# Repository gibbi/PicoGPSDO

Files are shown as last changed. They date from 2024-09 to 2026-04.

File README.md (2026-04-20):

# picoExtRef — GPS-disciplined OCXO reference (Pico)

RP2040 firmware that steers an OCXO via PWM (“DAC”), reads u-blox GNSS time over UART (UBX), and closes a two-stage servo: coarse steering from NAV-CLOCK and fine steering from TIM-TP `qErr`. A small Flask dashboard on the host tails USB CDC for live plots and tuning.

**Hardware upstream:** this tree is based on [gibbi/PicoGPSDO](https://github.com/gibbi/PicoGPSDO) (schematics, KiCad, and notes under `hardware/`). Presentation context: European GNU Radio Days 2024 — [talk on YouTube](https://www.youtube.com/watch?v=h3X4QuF_BUM).

---

## Web UI screenshot

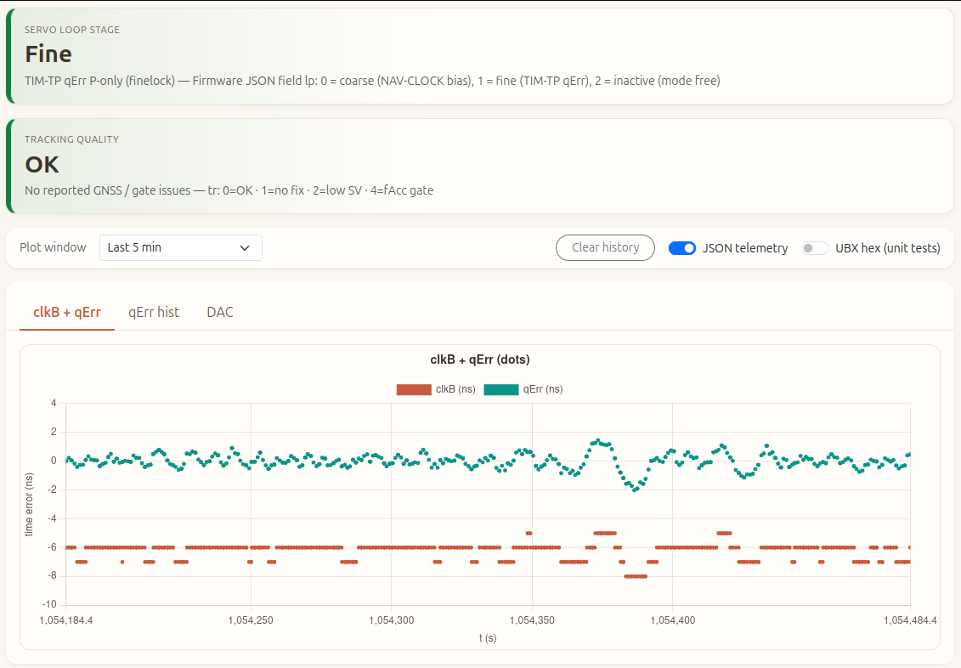
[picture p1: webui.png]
GPSDO web dashboard


## Repository layout and components

| Area | Role |
|---|---|
| **`src/main.c`** | Boot, PWM DAC / 26 MHz ref clock, main loop, JSON telemetry, USB CLI polling, fine-mode edge tracker integration, fractional DAC accumulation. |
| **`src/ubx.c`**, **`src/ubx_rx.c`** | UART RX (frame assembly + checksum), UBX decode, fills `current_gps_data` (NAV-CLOCK, TIM-TP, PVT, etc.). |
| **`include/ubx_clean.h`** | Shared GPS/UBX structs and packet layout used by the parser. |
| **`src/gpsdo_control.c`**, **`include/gpsdo_control.h`** | Finelock hysteresis, coarse/fine control outputs (`u_ns`), NAV-CLOCK bias handling, telemetry `tr` flags. |
| **`src/gpsdo_tune.c`**, **`include/gpsdo_tune.h`** | Runtime tunables and USB one-line CLI (`kp`, `fine_mode`, gates, etc.). |
| **`include/display.h`** | SSD1306 OLED over I2C (optional); live status text on the module. |
| **`pico_gpsdo_web.py`** | Flask host app: reads Pico USB serial, parses `{…}` telemetry, serves charts, tune forms, log tail, optional series clear. |
| **`pico.py`** | Developer entrypoint: `clean` / `build` / `flash` / `webserver` / `lint` (see script header for caveats on `build/` paths). |
| **`CMakeLists.txt`**, **`boards/`** | Pico SDK project, board hooks. |
| **`hardware/`** | From [PicoGPSDO](https://github.com/gibbi/PicoGPSDO): PCB and hardware documentation (see `hardware/Readme.md`). |
| **`tests/`** | Small host-side tests (e.g. UBX RX framing). |

---

## Data flow (short)

1. **u-blox** → UART0 → UBX frames → `current_gps_data` (`clkB`, `qErr`, `dac`, fix, etc.).
2. **Servo** (when `mode servo`): coarse on `clkD_bias` when bias steps; fine on `qErr` (P-only or edge mode) in finelock.
3. **USB CDC** → compact JSON lines for the host **web UI** and `printf` debugging.

---

## Quick start

```bash
# Firmware (needs Pico SDK in environment per Pico docs)
./pico.py build
./pico.py flash          # optional: ./pico.py flash --webserver

# Web dashboard only (USB serial to the Pico)
pip install -r requirements.txt
./pico.py webserver      # or: python3 pico_gpsdo_web.py … per pico.py usage
```

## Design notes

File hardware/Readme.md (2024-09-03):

# Hardware Description

This folder holds the hardware documentation for the 26MHz testbed. 

## Todo:

- [x] push kicad projects
- [ ] document antennuator values
- [ ] document ublox modification
- [ ] document oscillator swap

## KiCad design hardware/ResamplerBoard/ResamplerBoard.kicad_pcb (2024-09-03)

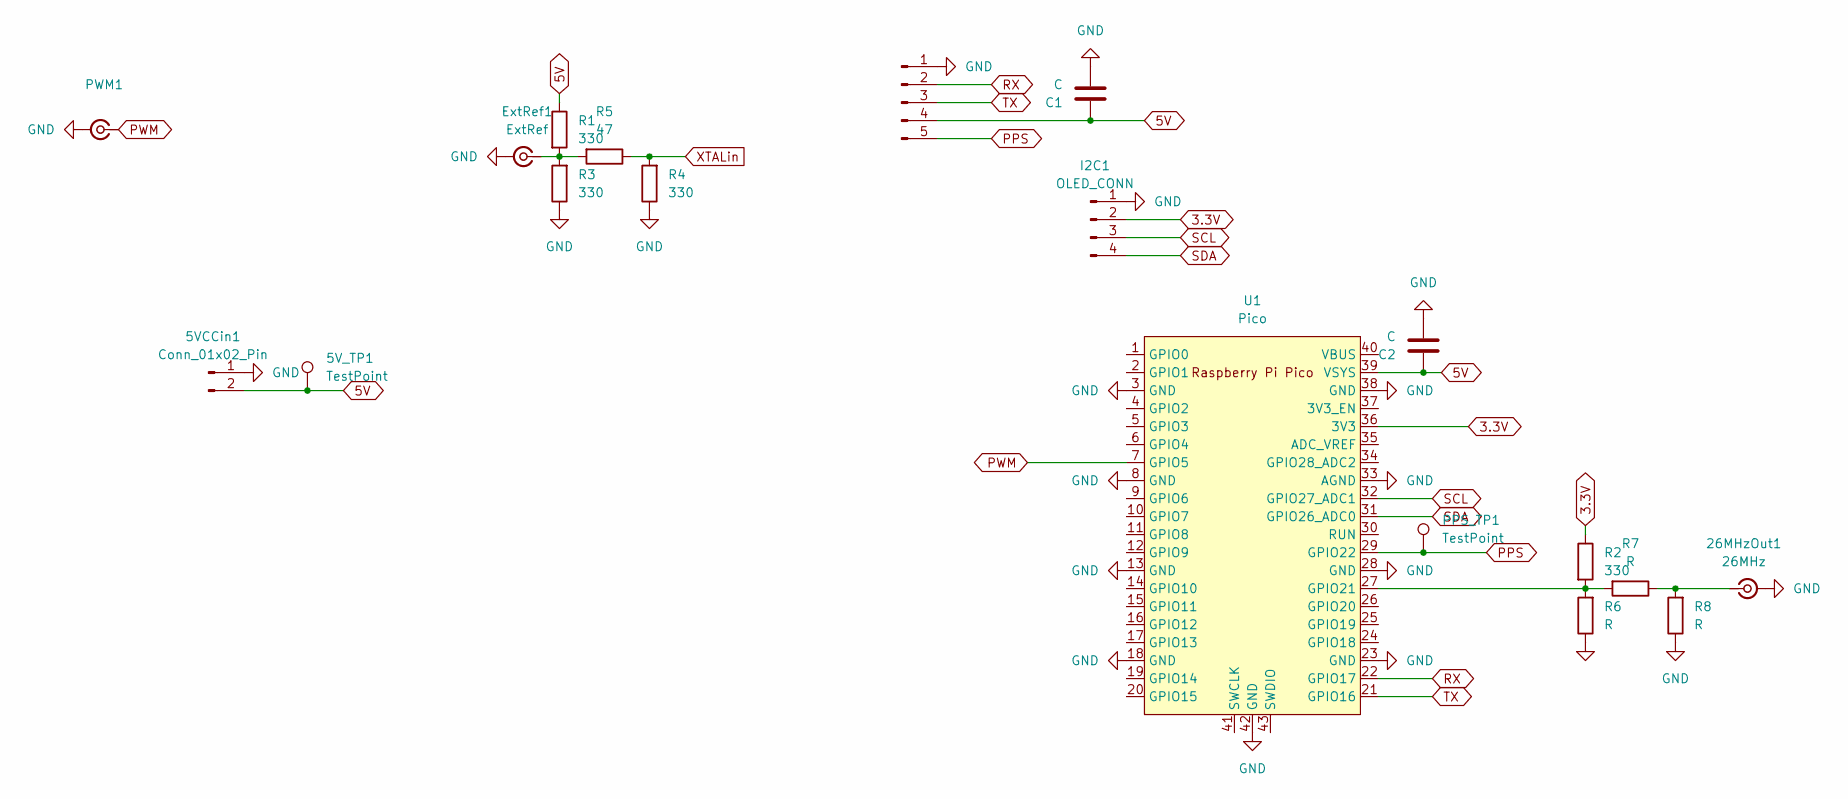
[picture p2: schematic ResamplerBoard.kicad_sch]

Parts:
5VCCin1: Conn_01x02_Pin; PinHeader_1x02_5VIN
5V_TP1: TestPoint; TestPoint_Pad_D2.0mm
26MHzOut1: 26MHz; SMA_EDGE_GIBBI
C1, C2: C; C_1210_3225Metric_Pad1.33x2.70mm_HandSolder
ExtRef1: ExtRef; SMA_EDGE_GIBBI
GPS_UART1: 9600; GPS_HEADER
I2C1: OLED_CONN; 128x64OLED
PPS_TP1: TestPoint; TestPoint_Pad_D2.0mm
PWM1: PWM; SMA_EDGE_GIBBI
R1, R2, R3, R4: 330; R_1210_3225Metric_Pad1.30x2.65mm_HandSolder
R5: 47; R_1210_3225Metric_Pad1.30x2.65mm_HandSolder
R6, R7, R8: R; R_1210_3225Metric_Pad1.30x2.65mm_HandSolder
U1: Pico; RPi_Pico_SMD_TH_NO_SILK_NO_HOLE

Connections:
3.3V: I2C1.2, R2.1, U1.36 (3V3)
5V: 5VCCin1.2, 5V_TP1.1, C1.1, C2.1, GPS_UART1.4, R1.1, U1.39 (VSYS)
GND: 5VCCin1.1, 26MHzOut1.2 (Ext), C1.2, C2.2, ExtRef1.2 (Ext), GPS_UART1.1, I2C1.1, PWM1.2 (Ext), R3.1, R4.1, R6.1, R8.1, U1.3 (GND), U1.8 (GND), U1.13 (GND), U1.18 (GND), U1.23 (GND), U1.28 (GND), U1.33 (AGND), U1.38 (GND), U1.42 (GND)
unnamed: 26MHzOut1.1 (In), R7.1, R8.2
unnamed: ExtRef1.1 (In), R1.2, R3.2, R5.2
unnamed: R2.2, R6.2, R7.2, U1.27 (GPIO21)
PPS: GPS_UART1.5, PPS_TP1.1, U1.29 (GPIO22)
PWM: PWM1.1 (In), U1.7 (GPIO5)
RX: GPS_UART1.2, U1.22 (GPIO17)
SCL: I2C1.3, U1.32 (GPIO27_ADC1)
SDA: I2C1.4, U1.31 (GPIO26_ADC0)
TX: GPS_UART1.3, U1.21 (GPIO16)
XTALin: R4.2, R5.1

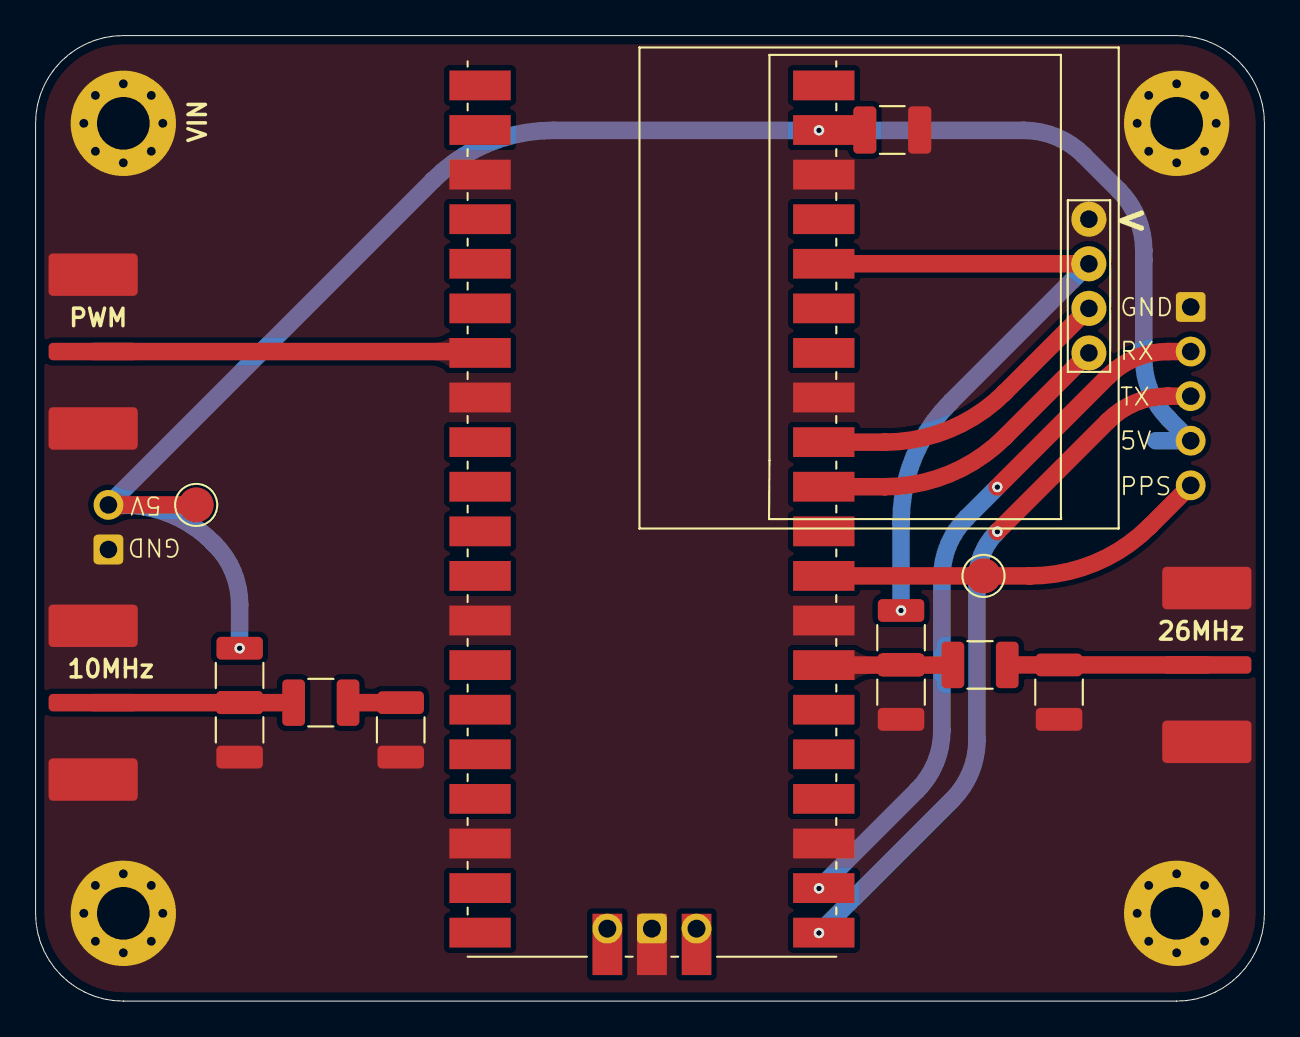
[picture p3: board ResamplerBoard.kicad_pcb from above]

Board: 2 copper layers, 70.0 x 55.0 mm, 19 parts (1 on the bottom side), 13 nets.

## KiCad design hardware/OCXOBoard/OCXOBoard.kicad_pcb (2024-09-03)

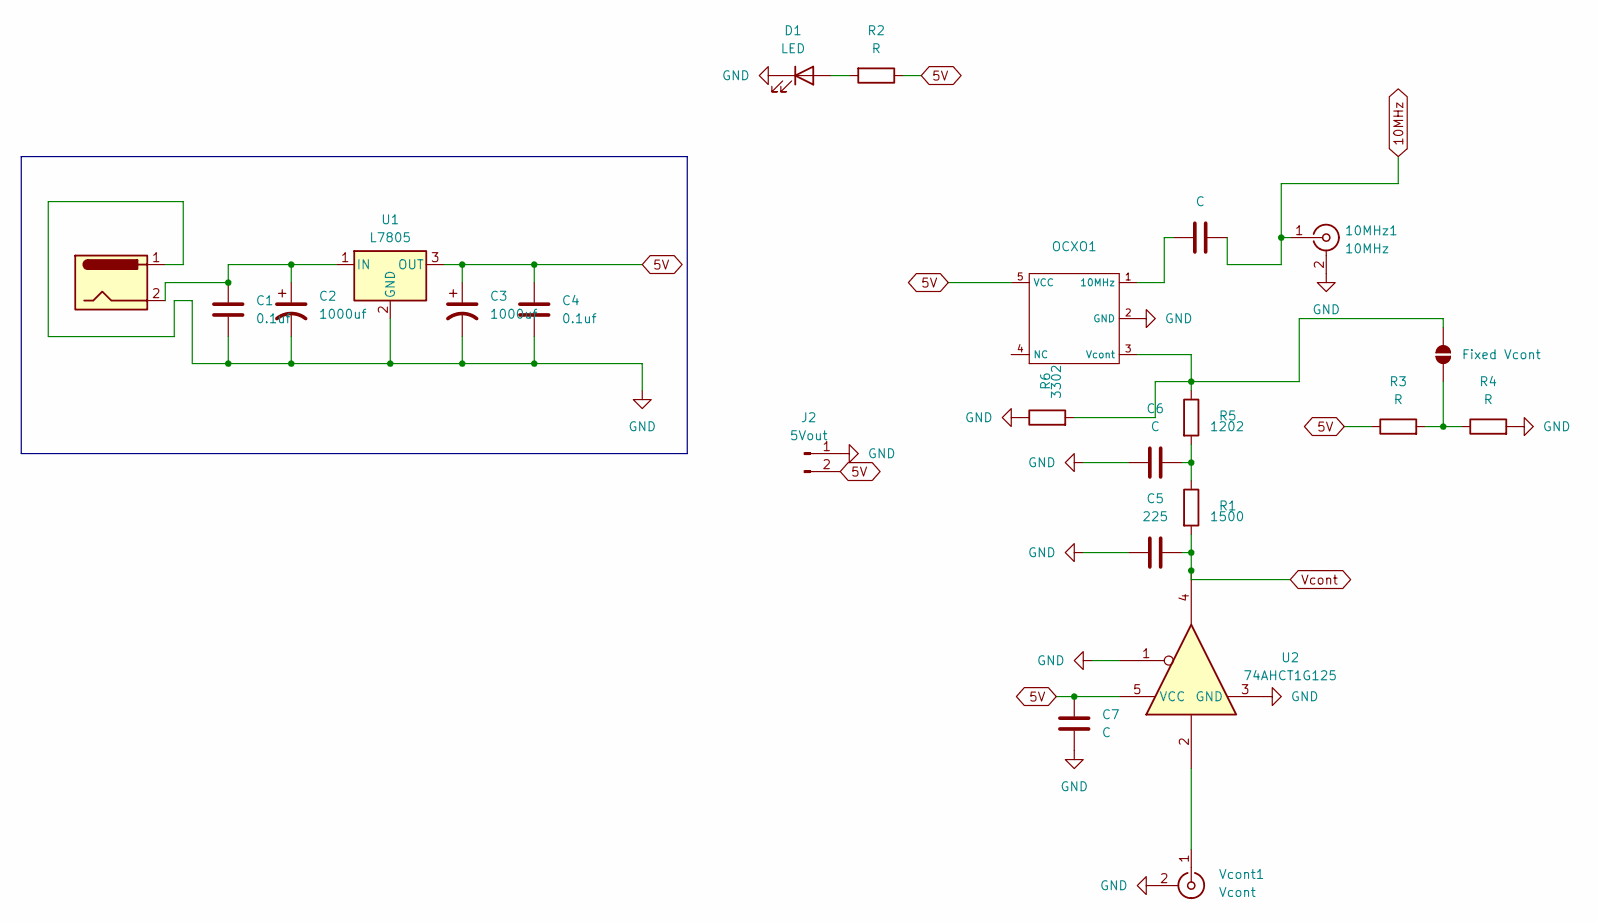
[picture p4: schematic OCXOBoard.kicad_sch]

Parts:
10MHz1: 10MHz; SMA_EDGE_GIBBI
C1, C4: 0.1uf; C_1210_3225Metric_Pad1.33x2.70mm_HandSolder
C2, C3: 1000uf; CP_EIA-7343-43_Kemet-X_Pad2.25x2.55mm_HandSolder
C5: 225; C_1210_3225Metric_Pad1.33x2.70mm_HandSolder
C6, C7: C; C_1210_3225Metric_Pad1.33x2.70mm_HandSolder
C8: C; C_0805_2012Metric_Pad1.18x1.45mm_HandSolder
D1: LED; D_1210_3225Metric_Pad1.42x2.65mm_HandSolder
FixedVcont1: Fixed Vcont; SolderJumper-2_P1.3mm_Open_RoundedPad1.0x1.5mm
J1: DC Connector; AMASS_XT30PW-M_1x02_P2.50mm_Horizontal
J2: 5Vout; Simple5V
OCXO1: MULTI_XO
R1: 1500; R_1210_3225Metric_Pad1.30x2.65mm_HandSolder
R2, R3, R4: R; R_1210_3225Metric_Pad1.30x2.65mm_HandSolder
R5: 1202; R_1210_3225Metric_Pad1.30x2.65mm_HandSolder
R6: 3302; R_1210_3225Metric_Pad1.30x2.65mm_HandSolder
U1: L7805; TO-7805
U2: 74AHCT1G125; SOT-23-5_HandSoldering
Vcont1: Vcont; SMA_EDGE_GIBBI

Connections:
5V: C3.1, C4.1, C7.2, J2.2, OCXO1.5 (VCC), R2.1, R3.1, U1.3 (OUT), U2.5 (VCC)
10MHz: 10MHz1.1 (In), C8.2
GND: 10MHz1.2 (Ext), C1.2, C2.2, C3.2, C4.2, C5.1, C6.1, C7.1, D1.1 (K), J1.1, J2.1, OCXO1.2 (GND), R4.2, R6.1, U1.2 (GND), U2.1, U2.3 (GND), Vcont1.2 (Ext)
unnamed: C6.2, R1.1, R5.2
unnamed: D1.2 (A), R2.2
unnamed 5: FixedVcont1.1 (A), R3.2, R4.1; also elsewhere on the board
unnamed 6: FixedVcont1.2 (B), OCXO1.3 (Vcont), R5.1, R6.2; also elsewhere on the board
unnamed: C8.1, OCXO1.1 (10MHz)
unnamed: C1.1, C2.1, J1.2, U1.1 (IN)
unnamed: U2.2, Vcont1.1 (In)
Vcont: C5.2, R1.2, U2.4

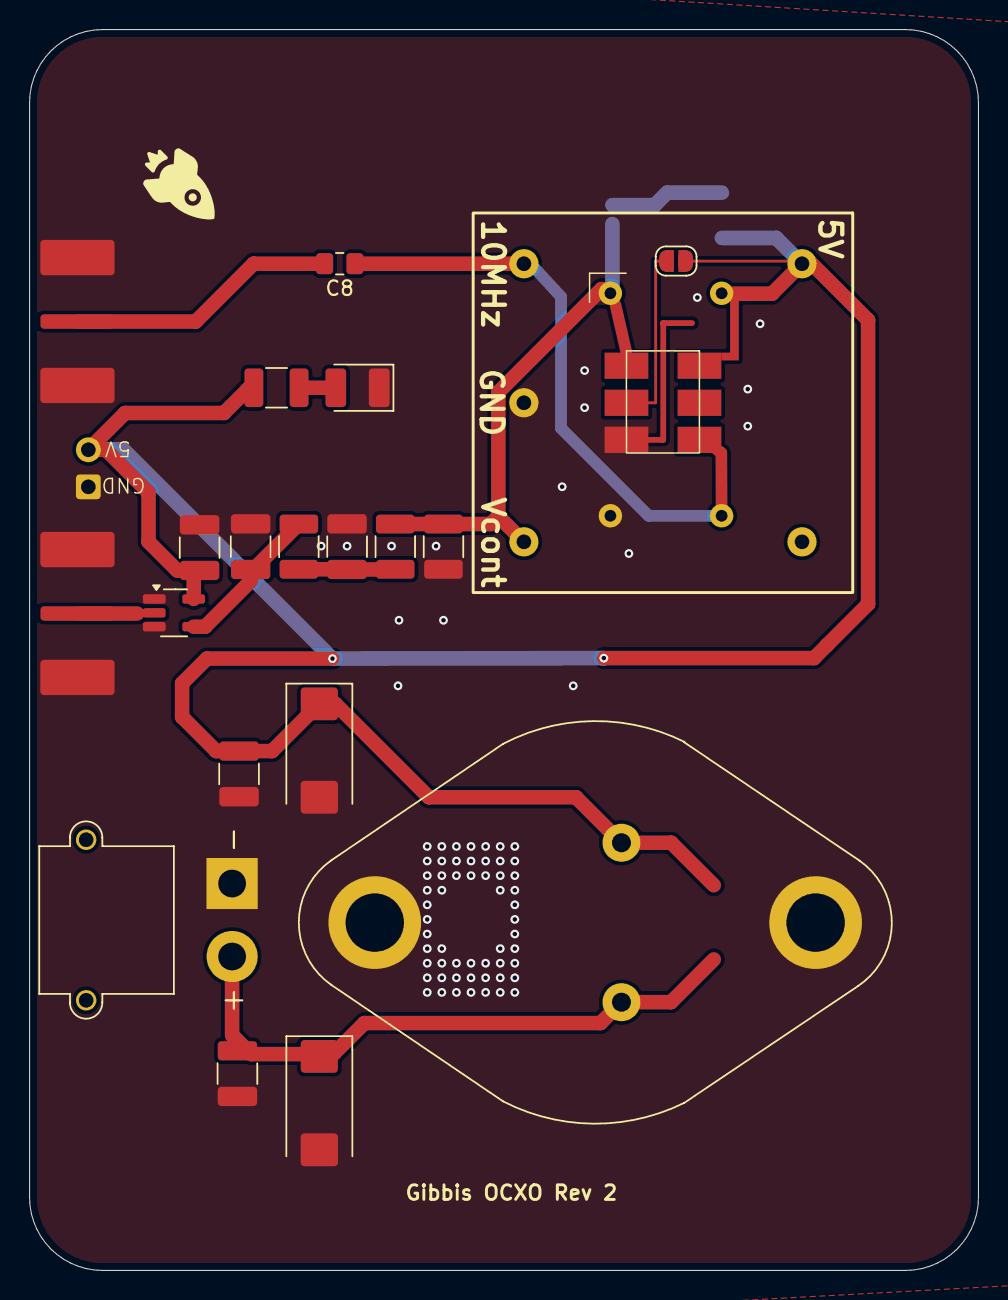
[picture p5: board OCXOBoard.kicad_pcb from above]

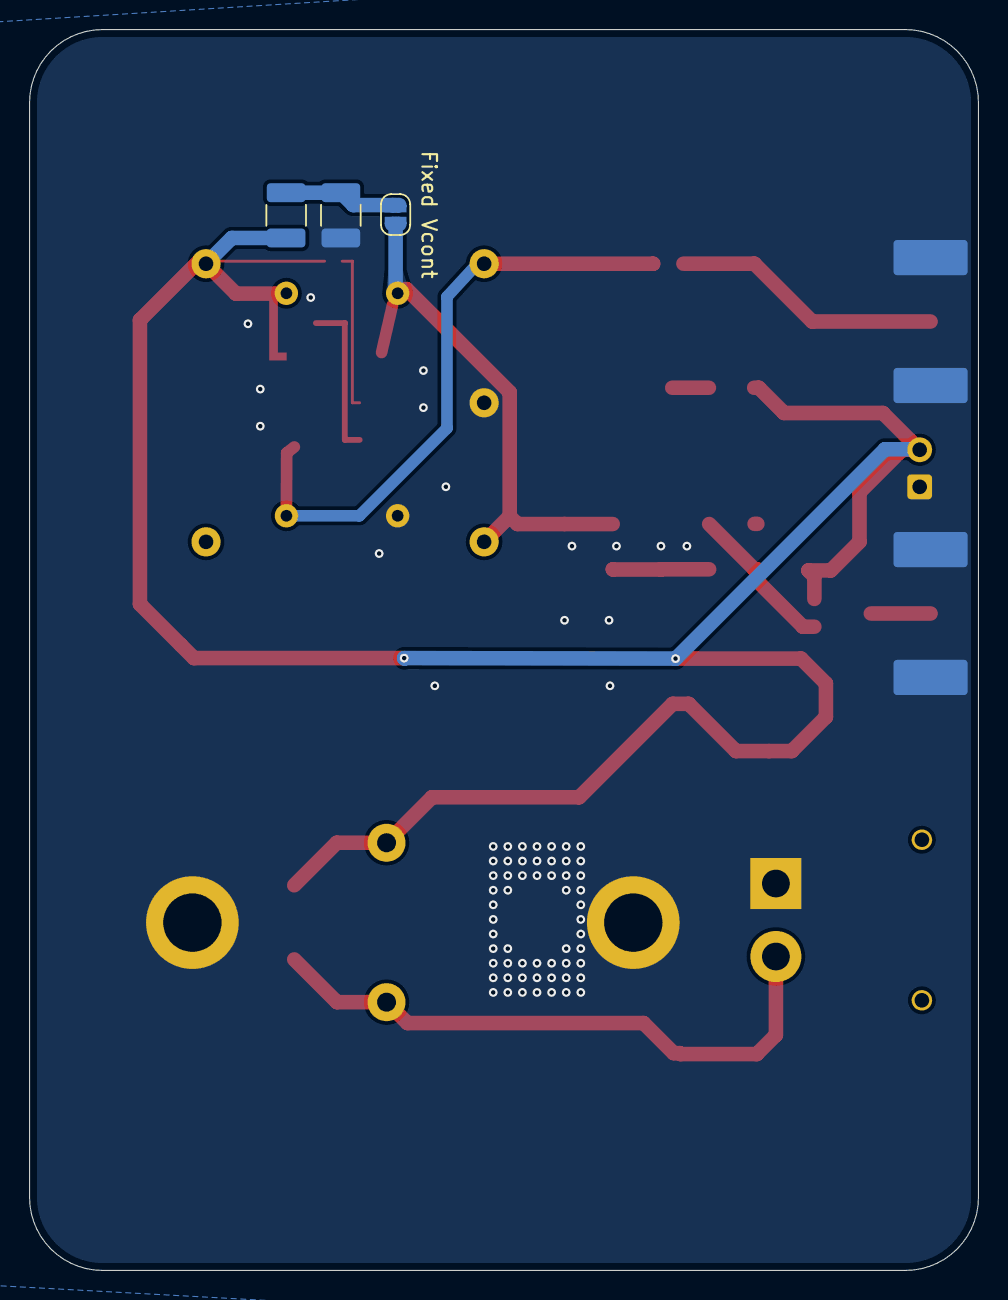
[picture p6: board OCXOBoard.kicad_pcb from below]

Board: 2 copper layers, 65.0 x 85.0 mm, 24 parts (3 on the bottom side), 11 nets.

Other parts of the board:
FixedVcont1#2: Fixed Vcont; SolderJumper-2_P1.3mm_Open_RoundedPad1.0x1.5mm

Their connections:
unnamed 5: FixedVcont1#2.1 (A); also elsewhere on the board
unnamed 6: FixedVcont1#2.2 (B); also elsewhere on the board

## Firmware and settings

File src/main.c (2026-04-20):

#include "display.h"
#include "hardware/clocks.h"

#include "pico/stdio.h"
#include "pico/stdlib.h"
#include "tusb.h"

#include "hardware/pwm.h"

#include <ctype.h>
#include <math.h>
#include <stdio.h>
#include <stdlib.h>
#include <string.h>

#define DATA_BITS 8
#define STOP_BITS 1
#define PARITY UART_PARITY_NONE
#define PWM_PIN 5
#define BAUDRATE 9600
#define USE_UART

#define UART_RX_PIN 17
#define UART_TX_PIN 16

/* GPIO21: CLK_GPOUT0 → 26 MHz RF reference for u-blox (clk_sys/4 @ 104 MHz SYS). */
#define GPS_REFCLK_OUT_PIN 21

#include "gpsdo_control.h"
#include "gpsdo_tune.h"
#include "ubx_clean.h"

#include "pico/error.h"

bool g_ubx_uart_hex_dump = false;
bool g_json_telemetry_print = true;

bool ssd1306_ok = false;

#if PICO_USB_BOOT_REENUM
/* TinyUSB + RP2040 DCD: toggling the pull-up makes the host see disconnect/reconnect (full re-enumeration). */
static void usb_host_force_reenumerate(void) {
	if (!tud_inited()) {
		return;
	}
	tud_disconnect();
	sleep_ms(100);
	tud_connect();
	sleep_ms(50);
}
#endif

//#define ALT_CPU

// for 26Mhz
#ifdef ALT_CPU
#define CLOCK_DIV 4.0
#else
#define CLOCK_DIV 1.0
#endif

void display() {
	char text[255];

	memset(buf, 0, SSD1306_BUF_LEN);

	sprintf(text, "clkB %d ", abs(current_gps_data.clkB));
	WriteString(buf, 0, 10, text);

	sprintf(text, "qErr %d ", abs(current_gps_data.qErr));
	WriteString(buf, 0, 18, text);

	sprintf(text, "fAcc %d ", current_gps_data.fAcc);
	WriteString(buf, 0, 26, text);

	sprintf(text, "dac %d ", current_gps_data.dac);
	WriteString(buf, 0, 34, text);

	sprintf(text, "sats %d x %d ", current_gps_data.satellites_visible, current_gps_data.fix);
	WriteString(buf, 0, 42, text);

	sprintf(text, "qAge %.1f  ", (double)current_gps_data.qAge);
	WriteString(buf, 0, 50, text);

	//memset(buf, 0xFF, SSD1306_BUF_LEN);

	//DrawLine(buf, 0, 20, 128, 20, true);

	//DrawLine(buf, 0, 30, 128, 30, true);

	//DrawLine(buf, 0, 0, 128, 64, true);
	//DrawLine(buf, 0, 40, 128, 40, true);
	render(buf);
}

uint fullScale = 8192 * 4 / CLOCK_DIV;

static uint g_pwm_slice_for_manual;

/* Fractional DAC counts not yet applied (PWM is integer steps). */
static float g_dac_frac_accum;
/* Per-DAC learned local slope score: sign(score) is slope sign; magnitude is confidence. */
static int8_t g_qerr_slope_score_by_dac[32768 + 1];
static int32_t g_edge_last_dac;
static int32_t g_edge_last_qerr_ps;
static bool g_edge_has_prev;
static bool g_edge_eval_pending;
static int32_t g_edge_eval_countdown;
static int32_t g_edge_eval_window_samples;
static int32_t g_edge_eval_from_dac;
static int32_t g_edge_eval_from_qerr_ps;
static int32_t g_edge_eval_step;
static int32_t g_qerr_hist_ps[64];
static int32_t g_qerr_hist_pos;
static int32_t g_qerr_hist_count;
static bool g_seen_nonzero_qerr;
static void fine_edge_reset(void);

static void setDAC_hw(uint slice, uint32_t dac) {
	if (dac > fullScale) {
		dac = fullScale;
	}
	pwm_set_chan_level(slice, PWM_PIN, dac);
	current_gps_data.dac = dac;
	current_gps_data.adjustDac = false;
}

void setDAC(uint slice, uint32_t dac) {
	g_dac_frac_accum = 0.0f;
	fine_edge_reset();
	setDAC_hw(slice, dac);
}

static void apply_manual_dac(uint32_t dac) {
	setDAC(g_pwm_slice_for_manual, dac);
}

float deltaToDac(float delta_ns) {  // 87ns = 1000 dac
	int32_t a = -delta_ns * 12.0481927711 / CLOCK_DIV;
	if (a > 4000 / CLOCK_DIV) { a = 4000 / CLOCK_DIV; }
	if (a < -4000 / CLOCK_DIV) { a = -4000 / CLOCK_DIV; }

	return (float)a;
}

static void dac_apply_delta(uint slice_num, float delta_counts) {
	g_dac_frac_accum += delta_counts;
	int32_t step = (int32_t)truncf(g_dac_frac_accum);
	if (step == 0) {
		return;
	}
	g_dac_frac_accum -= (float)step;

	int32_t old_dac = (int32_t)current_gps_data.dac;
	int64_t nd = (int64_t)old_dac + (int64_t)step;
	if (nd < 0) {
		nd = 0;
	}
	if (nd > (int64_t)fullScale) {
		nd = fullScale;
	}
	int32_t new_dac = (int32_t)nd;
	int32_t applied_delta = new_dac - old_dac;
	if (applied_delta != step) {
		g_dac_frac_accum += (float)(step - applied_delta);
	}
	setDAC_hw(slice_num, (uint32_t)new_dac);
}

static int32_t sign_i32(int32_t x) {
	if (x > 0) {
		return 1;
	}
	if (x < 0) {
		return -1;
	}
	return 0;
}

static int8_t clamp_i8(int32_t x) {
	if (x > 127) {
		return 127;
	}
	if (x < -127) {
		return -127;
	}
	return (int8_t)x;
}

static int32_t abs_i32(int32_t x) {
	return x >= 0 ? x : -x;
}

static void fine_edge_update_score_at(int32_t dac, int32_t delta) {
	if (dac < 0 || dac > 32768 || delta == 0) {
		return;
	}
	int32_t s = (int32_t)g_qerr_slope_score_by_dac[dac];
	/* Slow forgetting so the map can adapt over days. */
	if (s > 0) {
		s--;
	} else if (s < 0) {
		s++;
	}
	s += delta;
	g_qerr_slope_score_by_dac[dac] = clamp_i8(s);
}

static void fine_edge_reset(void) {
	memset(g_qerr_slope_score_by_dac, 0, sizeof(g_qerr_slope_score_by_dac));
	g_edge_last_dac = 0;
	g_edge_last_qerr_ps = 0;
	g_edge_has_prev = false;
	g_edge_eval_pending = false;
	g_edge_eval_countdown = 0;
	g_edge_eval_window_samples = 0;
	g_edge_eval_from_dac = 0;
	g_edge_eval_from_qerr_ps = 0;
	g_edge_eval_step = 0;
	g_qerr_hist_pos = 0;
	g_qerr_hist_count = 0;
}

static void qerr_hist_push(int32_t qerr_ps) {
	g_qerr_hist_ps[g_qerr_hist_pos] = qerr_ps;
	g_qerr_hist_pos = (g_qerr_hist_pos + 1) % 64;
	if (g_qerr_hist_count < 64) {
		g_qerr_hist_count++;
	}
}

static bool qerr_hist_get_n_ago(int32_t n, int32_t* out_qerr_ps) {
	if (n < 0 || n >= g_qerr_hist_count || out_qerr_ps == NULL) {
		return false;
	}
	int32_t idx = g_qerr_hist_pos - 1 - n;
	while (idx < 0) {
		idx += 64;
	}
	*out_qerr_ps = g_qerr_hist_ps[idx];
	return true;
}

static void fine_edge_arm_eval(int32_t dac_before, int32_t qerr_before_ps, int32_t applied_step, const gpsdo_tune_t* tune) {
	int32_t n = tune->fine_edge_eval_samples;
	if (n < 1) {
		n = 1;
	}
	g_edge_eval_pending = true;
	g_edge_eval_countdown = n;
	g_edge_eval_window_samples = n;
	g_edge_eval_from_dac = dac_before;
	g_edge_eval_from_qerr_ps = qerr_before_ps;
	g_edge_eval_step = applied_step;
}

static void fine_edge_track_observation(int32_t dac, int32_t qerr_ps) {
	qerr_hist_push(qerr_ps);

	if (g_edge_eval_pending) {
		g_edge_eval_countdown--;
		if (g_edge_eval_countdown <= 0) {
			int32_t ddac = g_edge_eval_step;
			int32_t q_n_ago = g_edge_eval_from_qerr_ps;
			/* Explicit sliding-window evaluation: qErr(now) - qErr(now-N samples). */
			if (!qerr_hist_get_n_ago(g_edge_eval_window_samples, &q_n_ago)) {
				q_n_ago = g_edge_eval_from_qerr_ps;
			}
			int32_t dq = qerr_ps - q_n_ago;
			if (ddac != 0 && dq != 0) {
				int64_t prod = (int64_t)ddac * (int64_t)dq;
				int32_t slope_sign = (prod > 0) ? 1 : -1;
				fine_edge_update_score_at(dac, slope_sign * 4);
				fine_edge_update_score_at(g_edge_eval_from_dac, slope_sign * 4);

				/* If error kept the same sign and grew over the eval window, penalize this slope. */
				int32_t prev_abs = abs_i32(g_edge_eval_from_qerr_ps);
				int32_t now_abs = abs_i32(qerr_ps);
				if (sign_i32(g_edge_eval_from_qerr_ps) == sign_i32(qerr_ps) && now_abs > prev_abs + 20) {
					/* Strong inversion on wrong-way behavior to recover quickly. */
					fine_edge_update_score_at(dac, -slope_sign * 16);
					fine_edge_update_score_at(g_edge_eval_from_dac, -slope_sign * 16);
				}
			}
			g_edge_eval_pending = false;
			g_edge_eval_countdown = 0;
			g_edge_eval_window_samples = 0;
			g_edge_eval_step = 0;
		}
	}

	g_edge_last_dac = dac;
	g_edge_last_qerr_ps = qerr_ps;
	g_edge_has_prev = true;
}

/* Returns -1/0/+1 DAC step. Learns local qErr slope from observed DAC transitions. */
static int32_t fine_edge_pick_step(const gps_data* data, const gpsdo_tune_t* tune) {
	(void)tune;

	int32_t dac = (int32_t)data->dac;
	int32_t slope = 0;
	if (dac >= 0 && dac <= 32768) {
		slope = sign_i32((int32_t)g_qerr_slope_score_by_dac[dac]);
	}
	if (slope == 0 && dac > 0 && dac <= 32768) {
		slope = sign_i32((int32_t)g_qerr_slope_score_by_dac[dac - 1]);
	}
	if (slope == 0 && dac >= 0 && dac < 32768) {
		slope = sign_i32((int32_t)g_qerr_slope_score_by_dac[dac + 1]);
	}
	if (slope == 0) {
		/* Fallback for startup until slope map is learned. */
		slope = 1;
	}

	/* Reduce qErr magnitude: step direction is opposite sign(qErr) under learned slope. */
	int32_t qsign = sign_i32(data->qErr);
	int32_t desired = -qsign * slope;
	if (desired > 1) {
		desired = 1;
	}
	if (desired < -1) {
		desired = -1;
	}
	if (dac <= 0 && desired < 0) {
		desired = 0;
	}
	if (dac >= (int32_t)fullScale && desired > 0) {
		desired = 0;
	}
	return desired;
}

/* USB CDC: one line per command (see gpsdo_tune_try_cli_line). */
static void poll_usb_tune_cli(void) {
	static char line_buf[96];
	static size_t line_len;

	for (;;) {
		int c = getchar_timeout_us(0);
		if (c == PICO_ERROR_TIMEOUT) {
			break;
		}
		if (c == '\r' || c == '\n') {
			if (line_len > 0) {
				line_buf[line_len] = '\0';
				if (!gpsdo_tune_try_cli_line(line_buf)) {
					if (strncmp(line_buf, "ubxhex ", 7) == 0) {
						char ch = line_buf[7];
						if (ch == '0' || ch == '1') {
							g_ubx_uart_hex_dump = (ch == '1');
							printf("[t] ubxhex %d\n", g_ubx_uart_hex_dump ? 1 : 0);
							stdio_flush();
						}
					} else if (strncmp(line_buf, "json ", 5) == 0) {
						char ch = line_buf[5];
						if (ch == '0' || ch == '1') {
							g_json_telemetry_print = (ch == '1');
							printf("[t] json %d\n", g_json_telemetry_print ? 1 : 0);
							stdio_flush();
						}
					} else if (isalpha((unsigned char)line_buf[0])) {
						printf("[t] ? help\n");
						stdio_flush();
					}
				}
				line_len = 0;
			}
		} else if (line_len < sizeof(line_buf) - 1) {
			line_buf[line_len++] = (char)c;
		}
	}
}

int main() {
	bool finelock = false;
	bool prev_finelock = false;
	bool prev_edge_mode = false;
	static float finelock_enter_accum_s;

	/* USB stdio must be first: printf before stdio_init_all() is silent. */
	stdio_init_all();
	printf("\nfw\n");
	stdio_flush();

	/*
	 * OCXO-servoed PWM (DAC) + 26 MHz GPS reference — right after first log so
	 * the u-blox sees a clock within a few ms of boot (only a short gap after reset).
	 */
	gpio_set_function(PWM_PIN, GPIO_FUNC_PWM);
	uint slice_num = pwm_gpio_to_slice_num(PWM_PIN);
	g_pwm_slice_for_manual = slice_num;
	gpsdo_tune_set_manual_dac_callback(apply_manual_dac);
	pwm_set_wrap(slice_num, fullScale);
	pwm_set_enabled(slice_num, true);
	/* 104 MHz clk_sys / 4 → 26 MHz on GPS_REFCLK_OUT_PIN */
	clock_gpio_init(GPS_REFCLK_OUT_PIN, CLOCKS_CLK_GPOUT0_CTRL_AUXSRC_VALUE_CLK_SYS, 4 / CLOCK_DIV);
	setDAC(slice_num, 17922 / CLOCK_DIV);
	printf("ref %u 26MHz\n", GPS_REFCLK_OUT_PIN);
	stdio_flush();

	const uint LED_PIN = PICO_DEFAULT_LED_PIN;

	printf("usb 500ms\n");
	stdio_flush();
	sleep_ms(500);

#if PICO_USB_BOOT_REENUM
	/* Do not printf() while disconnected — CDC is down. */
	usb_host_force_reenumerate();
	printf("usb reenum\n");
	stdio_flush();
#endif

	SSD1306_init();
	SSD1306_scroll(false);

	display();

	bool reset = true;

	if (reset) {
		while (true) {
			if (ubx_init()) {
				printf("ubx ok\n");
				stdio_flush();
				break;
			}
			printf("ubx retry 1s\n");
			stdio_flush();
			sleep_ms(1000);
		}
	} else {
		uart_init_ubx(38400);
	}
	gpsdo_tune_init_defaults();
	gpsdo_control_reset_state();
	fine_edge_reset();
	printf("[t] help|ver|mode|dac|…\n");
	gpsdo_tune_print_version_banner();
	stdio_flush();
	//	setDAC(slice_num, 18922);  // == 83

	//	setDAC(slice_num, 16922);  // == - 87
	current_gps_data.adjustDac = false;
	current_gps_data.newQerr = false;
	current_gps_data.newBias = false;
	g_seen_nonzero_qerr = false;

	gpio_init(LED_PIN);
	gpio_set_dir(LED_PIN, GPIO_OUT);
	gpio_put(LED_PIN, 1);
	uint32_t eval_duration = 5;

	uint32_t loop_count = 0;

	while (true) {
		/* UBX RX only via UART0 IRQ (ubx_poll in irq handler). Do not call ubx_poll() here:
		 * ubx_handle_byte() uses static parser state; IRQ + main-loop polling races and drops ACKs. */
		poll_usb_tune_cli();
		/* Heartbeat: early boot logs are lost before the host opens the CDC tty after flash. */
		loop_count++;
		if (loop_count % 30 == 0) {
			printf("[hb] %u\n", (unsigned)loop_count);
			stdio_flush();
		}

		sleep_ms(100);
		if (current_gps_data.newBias) {
			gpsdo_control_on_new_bias(&current_gps_data);
		}
		finelock = gpsdo_control_update_finelock(&current_gps_data, &gpsdo_tune, finelock, &finelock_enter_accum_s);
		const bool edge_mode_now = (gpsdo_tune.fine_mode == 1);
		/* Reset edge learner when leaving edge mode or dropping out of finelock into coarse. */
		if ((prev_edge_mode && !edge_mode_now) || (prev_finelock && !finelock)) {
			fine_edge_reset();
		}
		prev_edge_mode = edge_mode_now;
		prev_finelock = finelock;
		display();
		//current_gps_data.ticks++;
		/* One line per loop when TIM-TP and/or NAV-CLOCK updated. Always print the full struct
		 * snapshot so the host never sees long clkB gaps when only qErr refreshed this cycle. */
		if ((current_gps_data.newQerr || current_gps_data.newBias) && g_json_telemetry_print) {
			unsigned lp;
			if (gpsdo_run_mode == GPSDO_MODE_FREE) {
				lp = (unsigned)GPSDO_LOOP_INACTIVE;
			} else if (finelock) {
				lp = (unsigned)GPSDO_LOOP_FINE;
			} else {
				lp = (unsigned)GPSDO_LOOP_COARSE;
			}
			unsigned tr = gpsdo_control_track_flags(&current_gps_data, &gpsdo_tune);
			if (!g_seen_nonzero_qerr) {
				tr |= 8u;
			}
			printf(
					"{lp:%u,tr:%u,iT:%u,tMS:%u,tSub:%u,q:%d,cB:%d,cDb:%.3f,id:%.3f,cD:%d,tA:%u,fA:%u,dac:%u,sv:%u,tk:%u,fx:%u}\n",
					lp, tr, current_gps_data.iTOW, current_gps_data.towMS, current_gps_data.towSubMS,
					current_gps_data.qErr, current_gps_data.clkB, (double)current_gps_data.clkD_bias,
					(double)gpsdo_control_intended_drift(), current_gps_data.clkD,
					current_gps_data.tAcc, current_gps_data.fAcc, current_gps_data.dac,
					(unsigned)current_gps_data.satellites_visible, current_gps_data.ticks,
					(unsigned)current_gps_data.fix);
			stdio_flush();
		}

		if (current_gps_data.newQerr) {
			current_gps_data.newQerr = false;
			if (current_gps_data.qErr != 0) {
				g_seen_nonzero_qerr = true;
			}
			fine_edge_track_observation((int32_t)current_gps_data.dac, current_gps_data.qErr);

			if (gpsdo_run_mode == GPSDO_MODE_SERVO && finelock) {
				if (gpsdo_tune.fine_mode == 1) {
					if (!g_edge_eval_pending) {
						int32_t old_dac = (int32_t)current_gps_data.dac;
						int32_t step = fine_edge_pick_step(&current_gps_data, &gpsdo_tune);
						if (step != 0) {
							int32_t nd = old_dac + step;
							if (nd < 0) {
								nd = 0;
							}
							if (nd > (int32_t)fullScale) {
								nd = (int32_t)fullScale;
							}
							int32_t applied = nd - old_dac;
							if (applied != 0) {
								setDAC_hw(slice_num, (uint32_t)nd);
								fine_edge_arm_eval(old_dac, current_gps_data.qErr, applied, &gpsdo_tune);
							}
						}
					}
				} else {
					float u_ns = gpsdo_control_fine_u_ns(&current_gps_data, &gpsdo_tune);
					dac_apply_delta(slice_num, deltaToDac(u_ns));
				}
			}
		}

		/* Coarse: P on clkD_bias when clkB steps (adjustDac). */
		if (gpsdo_run_mode == GPSDO_MODE_SERVO && !finelock && current_gps_data.adjustDac) {
			bool facc_ok = (gpsdo_tune.facc_max_gate <= 0
					|| current_gps_data.fAcc <= (uint32_t)gpsdo_tune.facc_max_gate);
			if (facc_ok) {
				dac_apply_delta(slice_num, deltaToDac(gpsdo_control_coarse_u_ns(&current_gps_data, &gpsdo_tune)));
			}
		}

		if (current_gps_data.newBias) {
			current_gps_data.newBias = false;
		}

		//sprintf(text, "asd %u ", current_gps_data.dac_age);
		//WriteString(text, 25, 25, text);
		//render(buf);
	}
}

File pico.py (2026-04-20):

#!/usr/bin/env python3
"""
picoExtRef: ./pico.py clean | build | flash [--webserver] | webserver | all | lint [--check]
  build     cmake + make  →  build/firmware.elf
  flash     OpenOCD program build/firmware.elf; --webserver starts Flask dashboard
  webserver Flask dashboard only (USB CDC serial; no OpenOCD / reflash)
  all       build, then flash, then webserver (typical dev cycle)
  lint      clang-format using ./.clang-format; --check = dry-run for CI

  Web UI: pip install -r requirements.txt  (flask, pyserial)

  Build only in one clone path. CMake stores absolute paths in build/CMakeCache.txt — do not copy
  build/ between directories (e.g. ~/git/picoExtRef vs ~/orangebox/picoExtRef). If you develop over
  SSH, run ./pico.py on that host in the real checkout; do not reuse build/ from a different path
  (e.g. a local Cursor workspace vs the remote tree).
"""

from __future__ import annotations

import argparse
import errno
import glob
import multiprocessing
import os
import re
import shlex
import shutil
import subprocess
import sys
import time
from datetime import datetime
from pathlib import Path
from typing import NamedTuple, Optional

# --- logging (user pattern) -------------------------------------------------

loggingStartup = datetime.now()
loggingState = "build"
loggingExpectedDuration = None
guiCallback = None


class GuiState(NamedTuple):
    msg: str
    img_path: Optional[str] = None
    waiting_for_input: bool = False
    has_error: bool = False
    progress: Optional[object] = None


def showProgress():
    return None


class bcolors:
    HEADER = "\033[95m"
    OKBLUE = "\033[94m"
    OKCYAN = "\033[96m"
    OKGREEN = "\033[92m"
    WARNING = "\033[93m"
    FAIL = "\033[91m"
    ENDC = "\033[0m"
    BOLD = "\033[1m"
    UNDERLINE = "\033[4m"


class LogOBJ:
    def __init__(
        self,
        call,
        msg=None,
        image=None,
        nofail=False,
        silent=False,
        noTime=False,
        expectedDuration=None,
    ):
        global loggingExpectedDuration

        self.call = call
        self.msg = msg
        self.start = datetime.now()
        self.done = False
        self.nofail = nofail
        self.silent = silent
        self.stderr = ""
        self.stdout = ""

        elapsed = (datetime.now() - loggingStartup).total_seconds()

        if expectedDuration is not None:
            loggingExpectedDuration = elapsed + expectedDuration

        if not silent:
            if not noTime:
                print(
                    "{0}{1:10.2f} {2}".format(
                        bcolors.BOLD, elapsed, datetime.now().strftime("%H:%M:%S")
                    ),
                    end=" ",
                )

            print("{0}{1}{2}".format(bcolors.OKBLUE, loggingState, bcolors.ENDC), end=" ")

            display_msg = call if msg is None else msg
            print("{}".format(display_msg), end=" ", flush=True)

            if guiCallback is not None:
                try:
                    guiCallback(
                        GuiState(
                            display_msg,
                            img_path=image,
                            waiting_for_input=(loggingState == "userinput"),
                            has_error=(loggingState == "error"),
                            progress=showProgress(),
                        )
                    )
                except Exception:
                    pass

    def assignOutput(self, stdout, stderr):
        self.stderr = stderr
        self.stdout = stdout

    def ok(self):
        self.done = True
        if self.silent:
            return

        print("[ {}OK{} ]".format(bcolors.OKGREEN, bcolors.ENDC))

    def fail(self):
        self.done = True

        if self.silent:
            return

        if self.nofail:
            print("", flush=True)
            return

        print("[ {}FAIL{} ]".format(bcolors.FAIL, bcolors.ENDC), flush=True)

        print(self.call)

        if self.stdout != "":
            print(bcolors.WARNING + self.stdout + bcolors.ENDC, flush=True)
        if self.stderr != "":
            print(bcolors.FAIL + self.stderr + bcolors.ENDC, flush=True)

    def ignore(self):
        self.done = True

        if self.silent:
            return

        print("", flush=True)

    def __del__(self):
        if not self.done and not self.silent:
            raise Exception("logger died without result")


def _shell_run(cmd: str, *, cwd=None) -> tuple[int, bytes, bytes]:
    """Run `cmd` through bash -c (only subprocess callsite in this file)."""
    my_env = os.environ.copy()
    my_env["LC_ALL"] = "C"
    process = subprocess.Popen(
        ["bash", "-c", cmd],
        env=my_env,
        stdout=subprocess.PIPE,
        stderr=subprocess.PIPE,
        cwd=cwd,
    )
    stdout, stderr = process.communicate()
    code = process.returncode if process.returncode is not None else 0
    return code, stdout, stderr


def command(command: str, log=None, cwd=None, nofail=False, silent=False) -> bytes:
    logo = LogOBJ(command, log, nofail=nofail, silent=silent)
    code, stdout, stderr = _shell_run(command, cwd=cwd)
    logo.assignOutput(stdout.decode("utf-8", errors="replace"), stderr.decode("utf-8", errors="replace"))
    if code != 0:
        logo.fail()
        if log is None:
            raise Exception("command failed {}\n{}\n{}\n".format(command, stdout, stderr))
        else:
            print("command failed {}\n{}\n{}\n".format(command, stdout, stderr))
            raise Exception("Failure : " + log)
    logo.ok()
    return stdout


# --- project paths ----------------------------------------------------------

SCRIPT_DIR = Path(__file__).resolve().parent
BUILD_DIR = SCRIPT_DIR / "build"
DEFAULT_ELF = BUILD_DIR / "firmware.elf"
PICO_SDK_DEFAULT = Path.home() / "git" / "pico-sdk"

# Flash / TTY env defaults (see do_flash / find_firmware_tty)
DEFAULT_USB_VID = "1209"
DEFAULT_USB_PID = "0c01"
DEFAULT_VENDOR_SUBSTR = "orangebox"
DEFAULT_PRODUCT_SUBSTR = "picoextref"
DEFAULT_PICOPROBE_VID = "2e8a"
DEFAULT_PICOPROBE_PID = "000c"


def _env(k: str, default: str) -> str:
    v = os.environ.get(k)
    return v if v is not None and v != "" else default


def norm_usb_id(s: str) -> str:
    s = s.strip().lower()
    if s.startswith("0x"):
        s = s[2:]
    s = re.sub(r"[^0-9a-f]", "", s)
    if not s:
        return ""
    return f"{int(s, 16):04x}"


def _udev_properties(tty: Path) -> dict[str, str]:
    if not shutil.which("udevadm"):
        return {}
    cmd = f"udevadm info -q property -n {shlex.quote(str(tty))} 2>/dev/null"
    code, out_b, _ = _shell_run(cmd)
    if code != 0:
        return {}
    out = out_b.decode("utf-8", errors="replace")
    d: dict[str, str] = {}
    for line in out.splitlines():
        if "=" in line:
            k, _, v = line.partition("=")
            d[k] = v
    return d
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
